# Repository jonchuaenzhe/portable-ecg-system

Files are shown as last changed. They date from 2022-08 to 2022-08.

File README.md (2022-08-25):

Jan 2020 - Dec 2020
# IoT-enabled Portable 12-Lead ECG System

12-Lead ECGs are usually bulky and mounted on carts. This project in collaboration with NUH Emergency Department developed a portable version of it which displayed ECG tracings on a web-app to increase the efficiency of clinicians and comfort of patients. Take a look at the video below for a short demo of the system.

https://user-images.githubusercontent.com/59247141/186677922-14ab5f33-408b-436f-be4c-0afafe76f2a2.mp4

## Device

The Schematics and Layout of the circuit board design can be viewed directly in the "device" folder as PDF files.

"main.cpp" contains the firmware for the device, which runs on an ESP32 chip. It requires some commonly used ESP32 libraries not included in the "device" folder.

## Web Dashboard

The "app" folder houses both the client and server components of the MERN stack.

### Installation

Install dependencies for frontend by entering the frontend folder and running:
```
yarn install
```
Install dependencies for backend by entering the backend folder and running:
```
npm install
```

### Running Locally

To start the frontend application, enter the frontend folder and run:
```
yarn start
```
This runs the app in the development mode. Open [http://localhost:3000](http://localhost:3000) to view it in the browser. The page will reload if you make edits. You will also see any lint errors in the console.

To start the backend application, enter the backend folder on a separate terminal and run:
```
npm dev
```

### Deploying

The entire stack is deployed using Docker. Docker images are uploaded onto DockerHub and `docker-compose.prd.yml` is uploaded onto the server. To deploy the application, ssh into the server and run the docker-compose file:
```
ssh root@128.199.106.255
docker-compose -f docker-compose.prd.yml up -d --build
```

This will create a "docker network" and attach the three running containers (consisting of the client listening at port `3000`, server listening at port `5000` and mongo database listening at port `27017` on `mongo`) to it.

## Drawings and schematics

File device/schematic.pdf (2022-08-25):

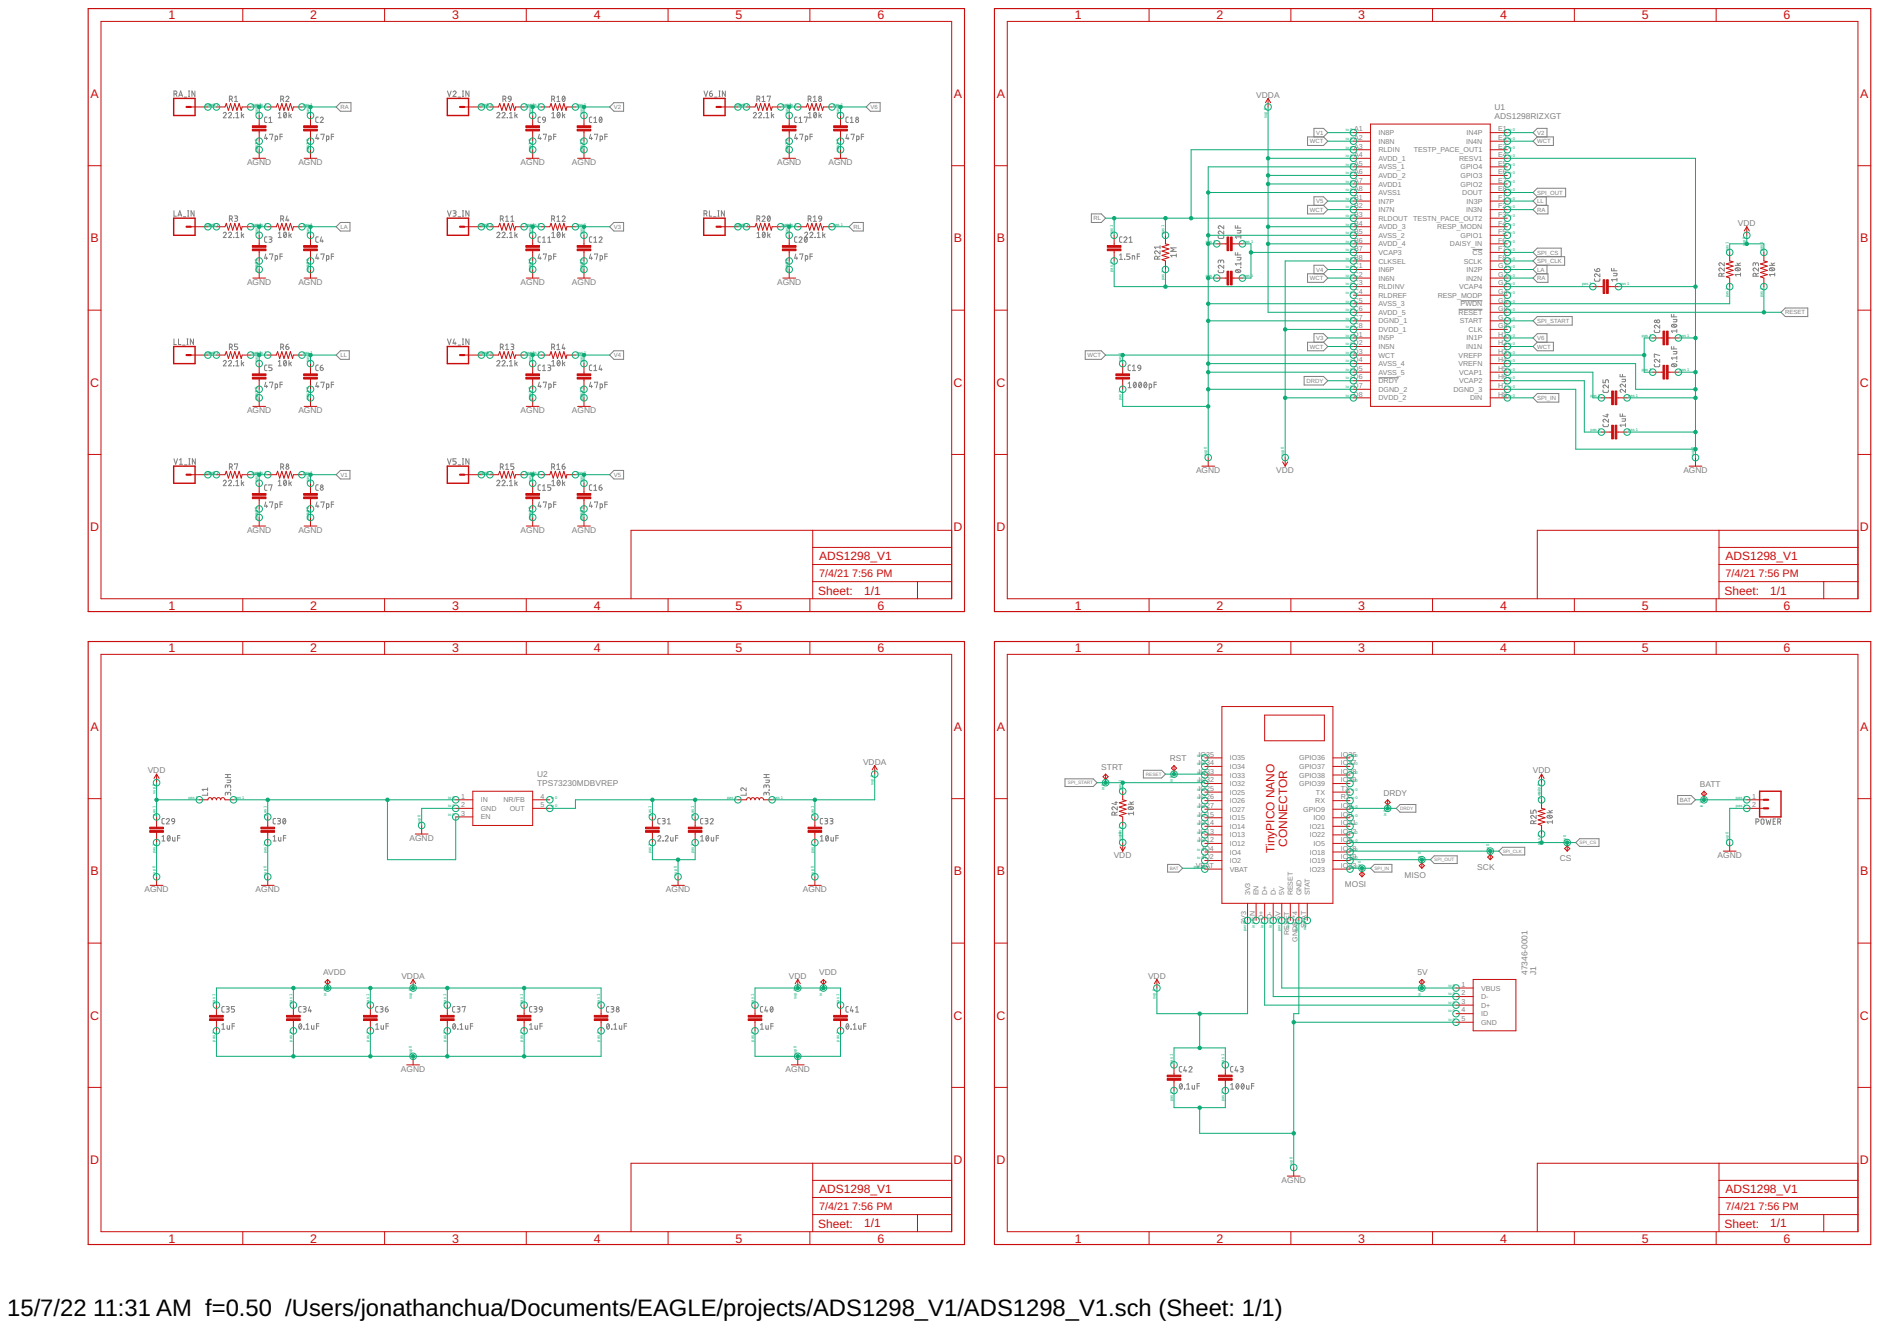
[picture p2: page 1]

WCT WCT WCT WCT B2 io 0 io 0 io 0 | RLDOUT B3 AVDD_3 B4 AVSS_2 B5 AVDD_4 B6 VCAP3 B7 CLKSEL B8 | WCT F2 TESTN_PACE_OUT2 F3 RESP_MODN io 0 RA io 0 F4 GPIO1 F5 DAISY_IN io 0 io 0 F6 CS io 0 F7 SCLK io 0 SPI_CS SPI_CLK LA

io 0
io 0 | | io 0 io 0 io 0 io 0 SPI_OUT LL

io 0 | F8 io 0

io 0 | | H4 VCAP1 H5 VCAP2 H6 DGND_3 H7 DIN io 0

io 0 | | io 0
io 0 | | H8 io 0

RESET RESET GND GND$1*4

15/7/22 11:31 AM f=0.50 /Users/jonathanchua/Documents/EAGLE/projects/ADS1298_V1/ADS1298_V1.sch (Sheet: 1/1)

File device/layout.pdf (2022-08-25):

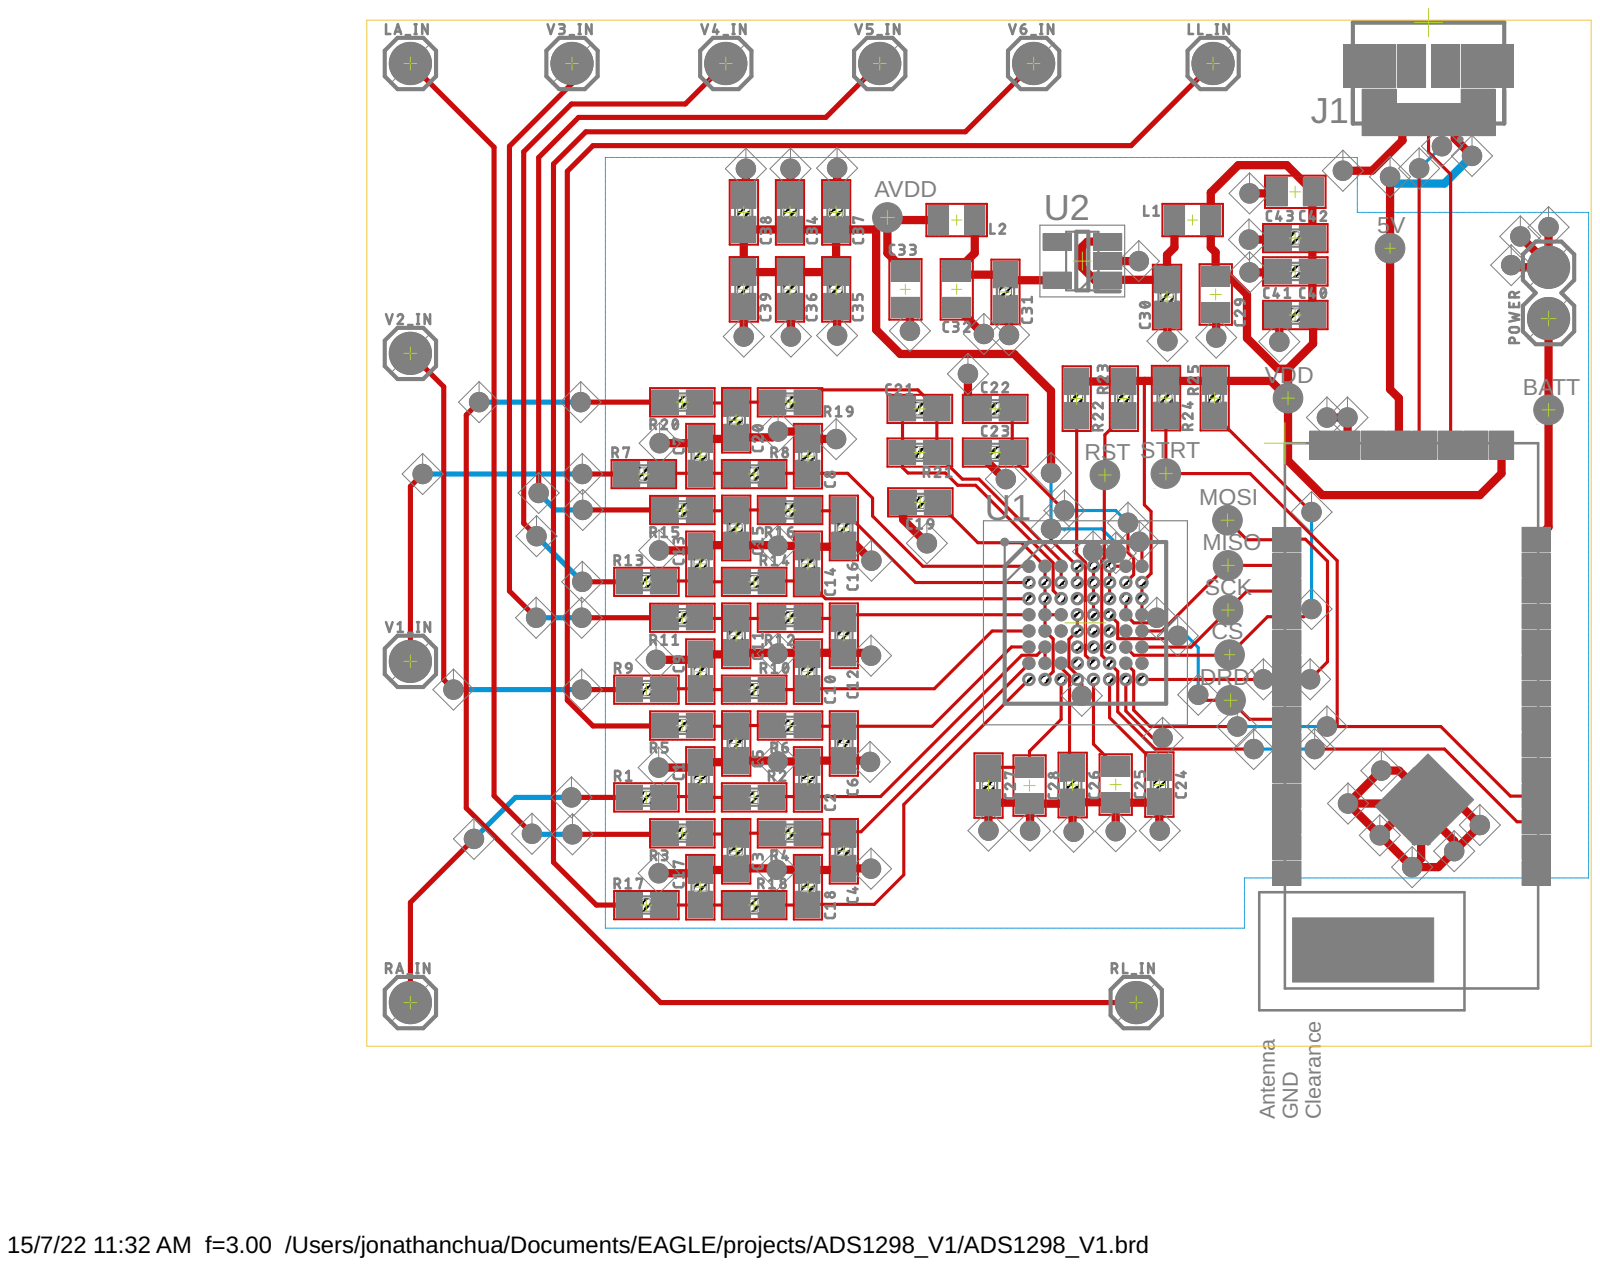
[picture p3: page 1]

15/7/22 11:32 AM f=3.00 /Users/jonathanchua/Documents/EAGLE/projects/ADS1298_V1/ADS1298_V1.brd

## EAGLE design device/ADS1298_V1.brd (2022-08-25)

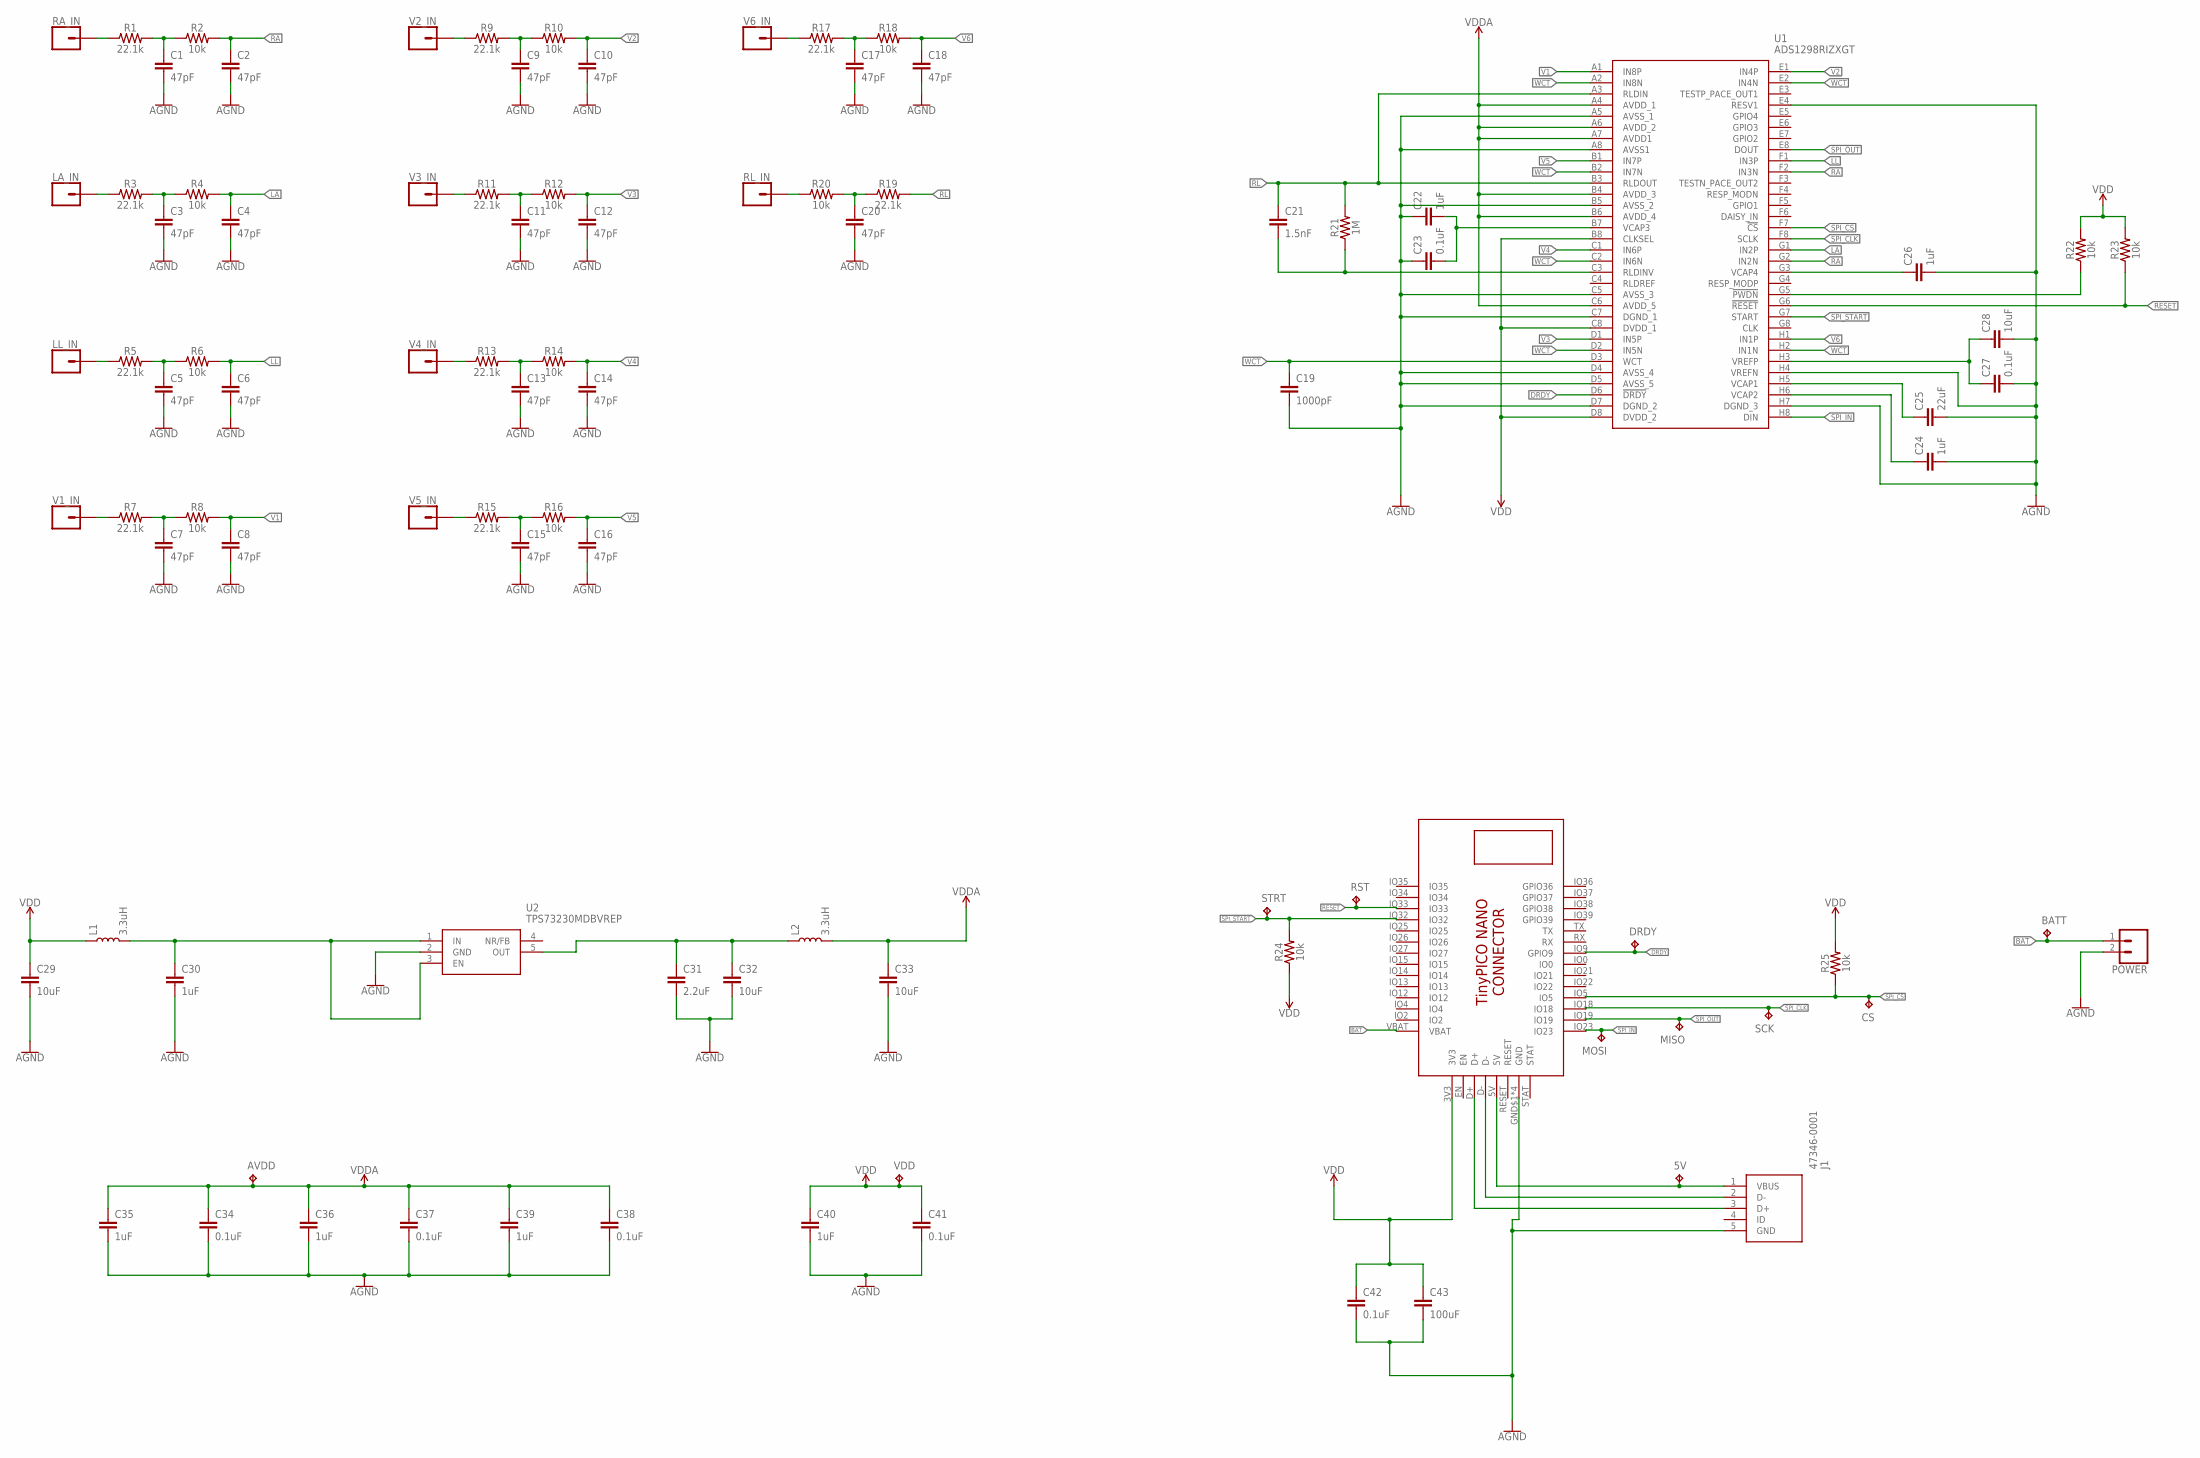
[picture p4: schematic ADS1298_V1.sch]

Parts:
5V: TPB1,27; B1,27
AVDD: TPB1,27; B1,27
BATT: TPB1,27; B1,27
C1, C2, C3, C4, C5, C6, C7, C8, C9, C10, C11, C12, C13, C14, C15, C16, C17, C18, C20: 47pF; 0603
C19: 1000pF; 0603
C21: 1.5nF; 0603
C22, C24, C26, C30, C35, C36, C39, C40: 1uF; 0603
C23, C27, C34, C37, C38, C41, C42: 0.1uF; 0603
C25: 22uF; 0805
C28, C29, C32, C33: 10uF; 0805
C31: 2.2uF; 0603
C43: 100uF; 0805
CS: TPB1,27; B1,27
DRDY: TPB1,27; B1,27
J1: 47346-0001
L1, L2: 3.3uH; 0805
LA_IN: CONN_01; 1X01
LL_IN: CONN_01; 1X01
MISO: TPB1,27; B1,27
MOSI: TPB1,27; B1,27
POWER: CONN_02; 1X02
R1, R3, R5, R7, R9, R11, R13, R15, R17, R19: 22.1k; 0603
R2, R4, R6, R8, R10, R12, R14, R16, R18, R20, R22, R23, R24, R25: 10k; 0603
R21: 1M; 0603
RA_IN: CONN_01; 1X01
RL_IN: CONN_01; 1X01
RST: TPB1,27; B1,27
SCK: TPB1,27; B1,27
STRT: TPB1,27; B1,27
U1: ADS1298RIZXGT; BGA64C80P8X8_800X800X145
U2: TPS73230MDBVREP; SOT95P280X145-5N
U3: TINYPICO-NANO-CONNECTOR
V1_IN, V2_IN, V3_IN, V4_IN, V5_IN, V6_IN: CONN_01; 1X01
VDD: TPB1,27; B1,27

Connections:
AGND: C1.2, C2.2, C3.2, C4.2, C5.2, C6.2, C7.2, C8.2, C9.2, C10.2, C11.2, C12.2, C13.2, C14.2, C15.2, C16.2, C17.2, C18.2, C19.2, C20.2, C22.1, C23.1, C24.2, C25.2, C26.2, C27.2, C28.2, C29.2, C30.2, C31.2, C32.2, C33.2, C34.2, C35.2, C36.2, C37.2, C38.2, C39.2, C40.2, C41.2, C42.2, C43.2, J1.5 (GND), POWER.2, U1.A5 (AVSS_1), U1.A8 (AVSS1), U1.B5 (AVSS_2), U1.C5 (AVSS_3), U1.C7 (DGND_1), U1.D4 (AVSS_4), U1.D5 (AVSS_5), U1.D7 (DGND_2), U1.E4 (RESV1), U1.H4 (VREFN), U1.H7 (DGND_3), U2.2 (GND), U3.GND$1 (GND), U3.GND$2 (GND), U3.GND$3 (GND), U3.GND$4 (GND)
BAT: BATT.TP, POWER.1, U3.VBAT
DRDY: DRDY.TP, U1.D6 (!DRDY), U3.IO9 (GPIO9)
LA: C4.1, R4.2, U1.G1 (IN2P)
LL: C6.1, R6.2, U1.F1 (IN3P)
unnamed: R1.1, RA_IN.1
unnamed: C1.1, R1.2, R2.1
unnamed: LA_IN.1, R3.1
unnamed: C3.1, R3.2, R4.1
unnamed: LL_IN.1, R5.1
unnamed: C5.1, R5.2, R6.1
unnamed: R7.1, V1_IN.1
unnamed: C7.1, R7.2, R8.1
unnamed: R9.1, V2_IN.1
unnamed: C9.1, R9.2, R10.1
unnamed: R11.1, V3_IN.1
unnamed: C11.1, R11.2, R12.1
unnamed: R13.1, V4_IN.1
unnamed: C13.1, R13.2, R14.1
unnamed: R15.1, V5_IN.1
unnamed: C15.1, R15.2, R16.1
unnamed: R17.1, V6_IN.1
unnamed: C17.1, R17.2, R18.1
unnamed: R20.1, RL_IN.1
unnamed: C20.1, R19.1, R20.2
unnamed: C21.2, R21.1, U1.C3 (RLDINV)
unnamed: C22.2, C23.2, U1.B7 (VCAP3)
unnamed: R22.1, U1.G5 (!PWDN)
unnamed: C24.1, U1.H6 (VCAP2)
unnamed: C27.1, C28.1, U1.H3 (VREFP)
unnamed: C25.1, U1.H5 (VCAP1)
unnamed: C26.1, U1.G3 (VCAP4)
unnamed: C31.1, C32.1, L2.1, U2.5 (OUT)
unnamed: J1.3 (D+), U3.D+
unnamed: J1.2 (D-), U3.D-
unnamed: 5V.TP, J1.1 (VBUS), U3.5V
unnamed: C30.1, L1.2, U2.1 (IN), U2.3 (EN)
RA: C2.1, R2.2, U1.F2 (IN3N), U1.G2 (IN2N)
RESET: R23.1, RST.TP, U1.G6 (!RESET), U3.IO33
RL: C21.1, R19.2, R21.2, U1.A3 (RLDIN), U1.B3 (RLDOUT)
SPI_CLK: SCK.TP, U1.F8 (SCLK), U3.IO18
SPI_CS: CS.TP, R25.1, U1.F7 (!CS), U3.IO5
SPI_IN: MOSI.TP, U1.H8 (DIN), U3.IO23
SPI_OUT: MISO.TP, U1.E8 (DOUT), U3.IO19
SPI_START: R24.2, STRT.TP, U1.G7 (START), U3.IO32
V1: C8.1, R8.2, U1.A1 (IN8P)
V2: C10.1, R10.2, U1.E1 (IN4P)
V3: C12.1, R12.2, U1.D1 (IN5P)
V4: C14.1, R14.2, U1.C1 (IN6P)
V5: C16.1, R16.2, U1.B1 (IN7P)
V6: C18.1, R18.2, U1.H1 (IN1P)
VDD: C29.1, C40.1, C41.1, C42.1, C43.1, L1.1, R22.2, R23.2, R24.1, R25.2, U1.B8 (CLKSEL), U1.C8 (DVDD_1), U1.D8 (DVDD_2), U3.3V3, VDD.TP
VDDA: AVDD.TP, C33.1, C34.1, C35.1, C36.1, C37.1, C38.1, C39.1, L2.2, U1.A4 (AVDD_1), U1.A6 (AVDD_2), U1.A7 (AVDD1), U1.B4 (AVDD_3), U1.B6 (AVDD_4), U1.C6 (AVDD_5)
WCT: C19.1, U1.A2 (IN8N), U1.B2 (IN7N), U1.C2 (IN6N), U1.D2 (IN5N), U1.D3 (WCT), U1.E2 (IN4N), U1.H2 (IN1N)

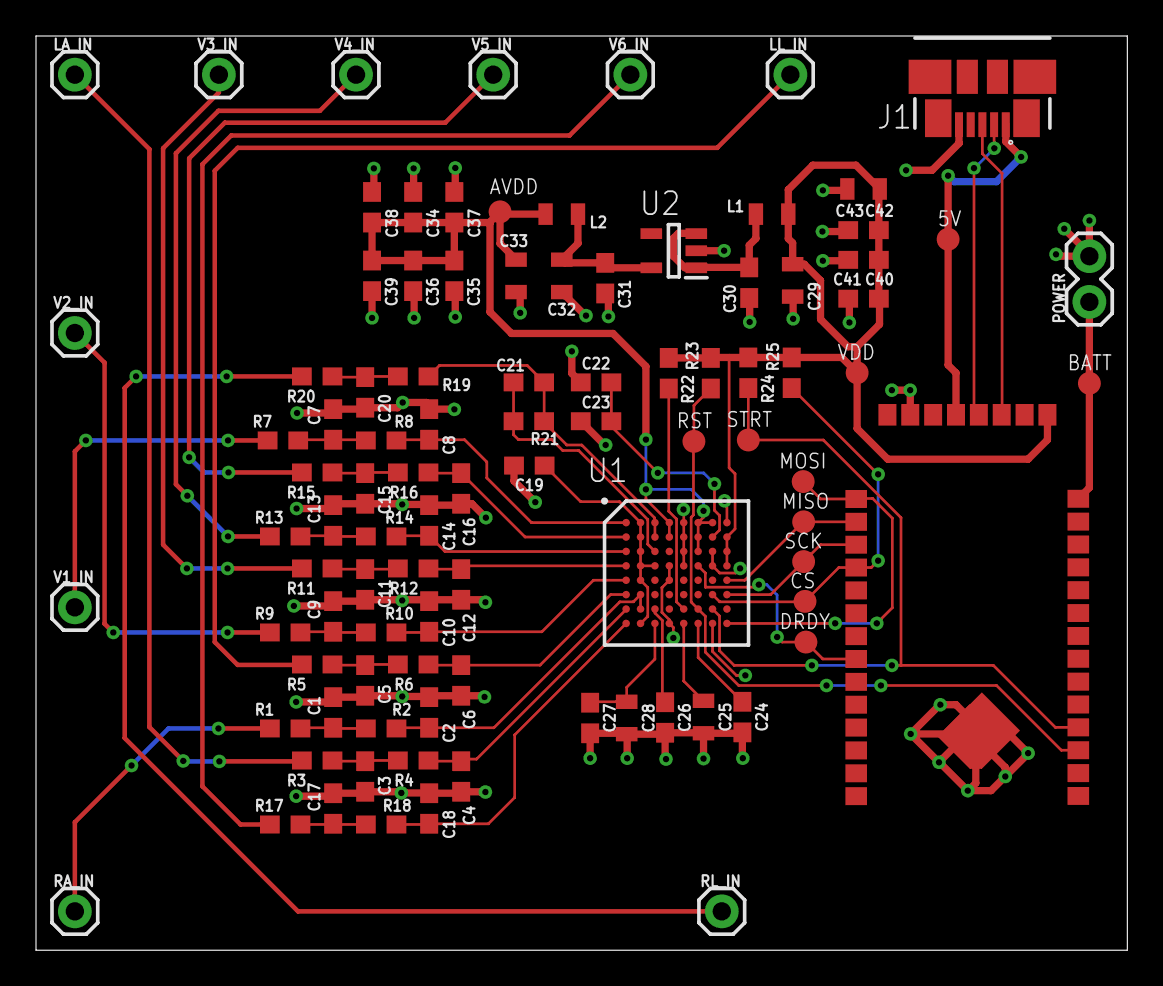
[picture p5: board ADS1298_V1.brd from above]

Board: 2 copper layers, 60.6 x 50.8 mm, 96 parts (0 on the bottom side), 54 nets.

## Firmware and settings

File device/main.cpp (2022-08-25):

short int ecg_array[4][2800];
char buf[60000];
int count = 0;

#include "esp32-hal-adc.h" // needed for adc pin reset
#include "soc/sens_reg.h" // needed for adc pin reset

#include <WiFi.h>
#include <HTTPClient.h>

#include <TinyPICO.h>
TinyPICO tp = TinyPICO();

RTC_DATA_ATTR uint64_t reg_b; // stores the rest state before Wifi is initialised

const char* ssid = "Jon Chua";
const char* password = "12345678";

//const char* ssid = "WSiot";
//const char* password = "wirelessecg";

float voltage;

void setup() {

  tp.DotStar_SetPixelColor(0, 0, 255);

  pinMode(15, INPUT);
  pinMode(25, INPUT);
  pinMode(26, INPUT);
  pinMode(27, INPUT);
  pinMode(21, OUTPUT);
  pinMode(22, OUTPUT);

  digitalWrite(21, LOW);
  digitalWrite(22, LOW);
  
  delay(1000);
  Serial.begin(115200);
  Serial.println("Wakey");

  reg_b = READ_PERI_REG(SENS_SAR_READ_CTRL2_REG);

  voltage = tp.GetBatteryVoltage();

  connect_to_wifi();

}


void loop() {
  
  read_store_ECG();

  send_data(0);

  delay(3000);

  send_data(1);

}


// reset the ADC2 pins so that it can read analog data from the ECG output
void reset_register() {

  // reset the ADC2 pins whenever a new ECG reading has to be collected
  WRITE_PERI_REG(SENS_SAR_READ_CTRL2_REG, reg_b);
  SET_PERI_REG_MASK(SENS_SAR_READ_CTRL2_REG, SENS_SAR2_DATA_INV);
  
}


void read_store_ECG(){
  for (int i = 0; i < 4; i++) {
    
    if (i%4 == 0) {
      digitalWrite(21, LOW);
      digitalWrite(22, LOW);
    }

    if (i%4 == 1) {
      digitalWrite(21, LOW);
      digitalWrite(22, HIGH);
    }

    if (i%4 == 2) {
      digitalWrite(21, HIGH);
      digitalWrite(22, LOW);
    }

    if (i%4 == 3) {
      digitalWrite(21, HIGH);
      digitalWrite(22, HIGH);
    }

    delay(3000);
    
    for (int j = 0; j < 700; j++) {
      reset_register();
      ecg_array[0][i*700 + j] = analogRead(15);
      reset_register();
      ecg_array[1][i*700 + j] = analogRead(27);
      reset_register();
      ecg_array[2][i*700 + j] = analogRead(26);
      reset_register();
      ecg_array[3][i*700 + j] = analogRead(25);
  
      delay(5);
    }

    delay(3000);
  }
  
}


void write_ecg_json() {
  count = -1;
  add_string("{\"ecg_data\":[");
  
  for (int i = 0; i < 4; i++) {
    add_string("[");
    
    for (int j = 0; j < 2800; j++) {
      add_string(String(ecg_array[i][j], DEC));
      
      if (j != 2799) {
        add_string(",");
      }
    }

    add_string("]");
    
    if (i != 3) {
      add_string(",");
    }
  }

  add_string("]}");
  end_buf();
}


void write_battery_json() {
  voltage = tp.GetBatteryVoltage();

  count = -1;
  add_string("{\"status\":\"alive\",\"voltage\":" + String(voltage, DEC) + "}");
  end_buf();
}


void connect_to_wifi() {
  WiFi.begin(ssid, password); 

  while (WiFi.status() != WL_CONNECTED) {
    delay(1000);
    Serial.println("Connecting to WiFi..");
  }
  
  Serial.print("WiFi connected with IP: ");
  Serial.println(WiFi.localIP());
}


void send_data(int x) {
  HTTPClient http;

  if (x == 0) {
    write_ecg_json();
    http.begin("http://128.199.106.255:5000/api/data/ecg/1");
  } else {
    write_battery_json();
    http.begin("http://128.199.106.255:5000/api/battery/1");
  }
  
  http.addHeader("Content-Type", "application/json");
  int httpResponseCode = http.POST(buf);

  Serial.println(buf);
  Serial.println(httpResponseCode);
}


void add_string(String txt) {
  int len = txt.length();
  
  for (int k = 0; k < len; k++) {
    count++;
    buf[count] = txt[k];
  }
}

void end_buf() {
  count++;
  buf[count] = '\0';
}

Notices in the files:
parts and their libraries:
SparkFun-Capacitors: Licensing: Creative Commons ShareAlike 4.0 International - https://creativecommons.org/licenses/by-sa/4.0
